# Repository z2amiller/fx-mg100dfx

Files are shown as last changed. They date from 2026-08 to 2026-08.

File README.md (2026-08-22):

# fx-mg100dfx

## MG100DFX Distortion (OD1/OD2)

A pedal port of the overdrive channel from the Marshall MG100DFX solid-state
amp, built for a [PedalPCB forum request][post]. The +/-15V bipolar original is
re-biased for single-supply operation.

### The circuit

Input stage (x11 non-inverting) into a high-gain summing stage that clips into
an antiparallel red/green LED pair across its feedback — even quiet playing
comes out almost as a square wave. The OD1/OD2 switch adds two extra input
branches (more gain, fuller voicing). Marshall-style treble/bass/middle stack,
contour, volume, then a x11 recovery stage.

### Power and headroom

- 9V: fully functional but not completely true to the original tone. The input stage rail-clips hot transients (above roughly 350mV peaks) before the LED clipper.
- 18V: reproduces the original amp's front-end dynamics essentially exactly (sim-verified: identical stage-1 swing to the +/-15V original). Electrolytics are 25V-rated for this.

### No-cap-mult (purist) build

Aggressive power rail filtering is done through a capacitor multiplier at the voltage input. This drops ~1V total between the reverse polarity protection diode and the capacitor multiplier.

If you have a clean supply and want to recover some of the headroom, you can
omit Q1 jumper Q1 pads 2-3 (B and E on the BC547 footprint), and fit 47R at
R23 (Just above the 4-pin connector at the south of the board) instead of 10k.
you get a plain RC filter (47R into ~200uF) — about 34dB less ripple filtering,
about 0.5V less drop. At 18V the saved drop is meaningless — this option is
parts-count preference, not tone.

### Parts notes

- D2/D3 clipping LEDs: use old-school GaP green (Vf ~2.0-2.2V). A modern InGaN green (2.6-2.9V) hits the op-amp rail before the LED clamps at 9V and kills the intended red/green asymmetric clipping.
- Q1 is BC547C (C-B-E). If substituting 2N5088, its pinout is E-B-C — check before soldering.
- Film caps in the signal path, ceramic disc for pF values, per the BOM.
- Hybrid I/O: populate EITHER the JST-PH headers (daughterboard style) OR the PedalPCB-style wire pads (IN at the bottom edge, VIN/GND at top). The daughterboard layout that supports this is at the [pedalfx repo][repo].

[post]: https://forum.pedalpcb.com/threads/help-needed-to-design-od1-od2-pedal-from-mg100dfx-amp.27087/
[repo]: https://github.com/z2amiller/pedalfx/tree/main/template

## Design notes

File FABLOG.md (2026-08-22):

# Fab Log

| Date | Board | Rev | Gen | Gerber SHA256 | JLC Order # | Notes |
|---|---|---|---|---|---|---|
| 2026-08-21T21:19 | fx-mg100dfx | 0.3 | 1 | 51ceb31effab | | |
| 2026-08-21T21:22 | fx-mg100dfx | 0.3 | 2 | 3eab3eaaba2f | | |
| 2026-08-22T16:02 | fx-mg100dfx | 0.4 | 3 | 9177482955ed | | |

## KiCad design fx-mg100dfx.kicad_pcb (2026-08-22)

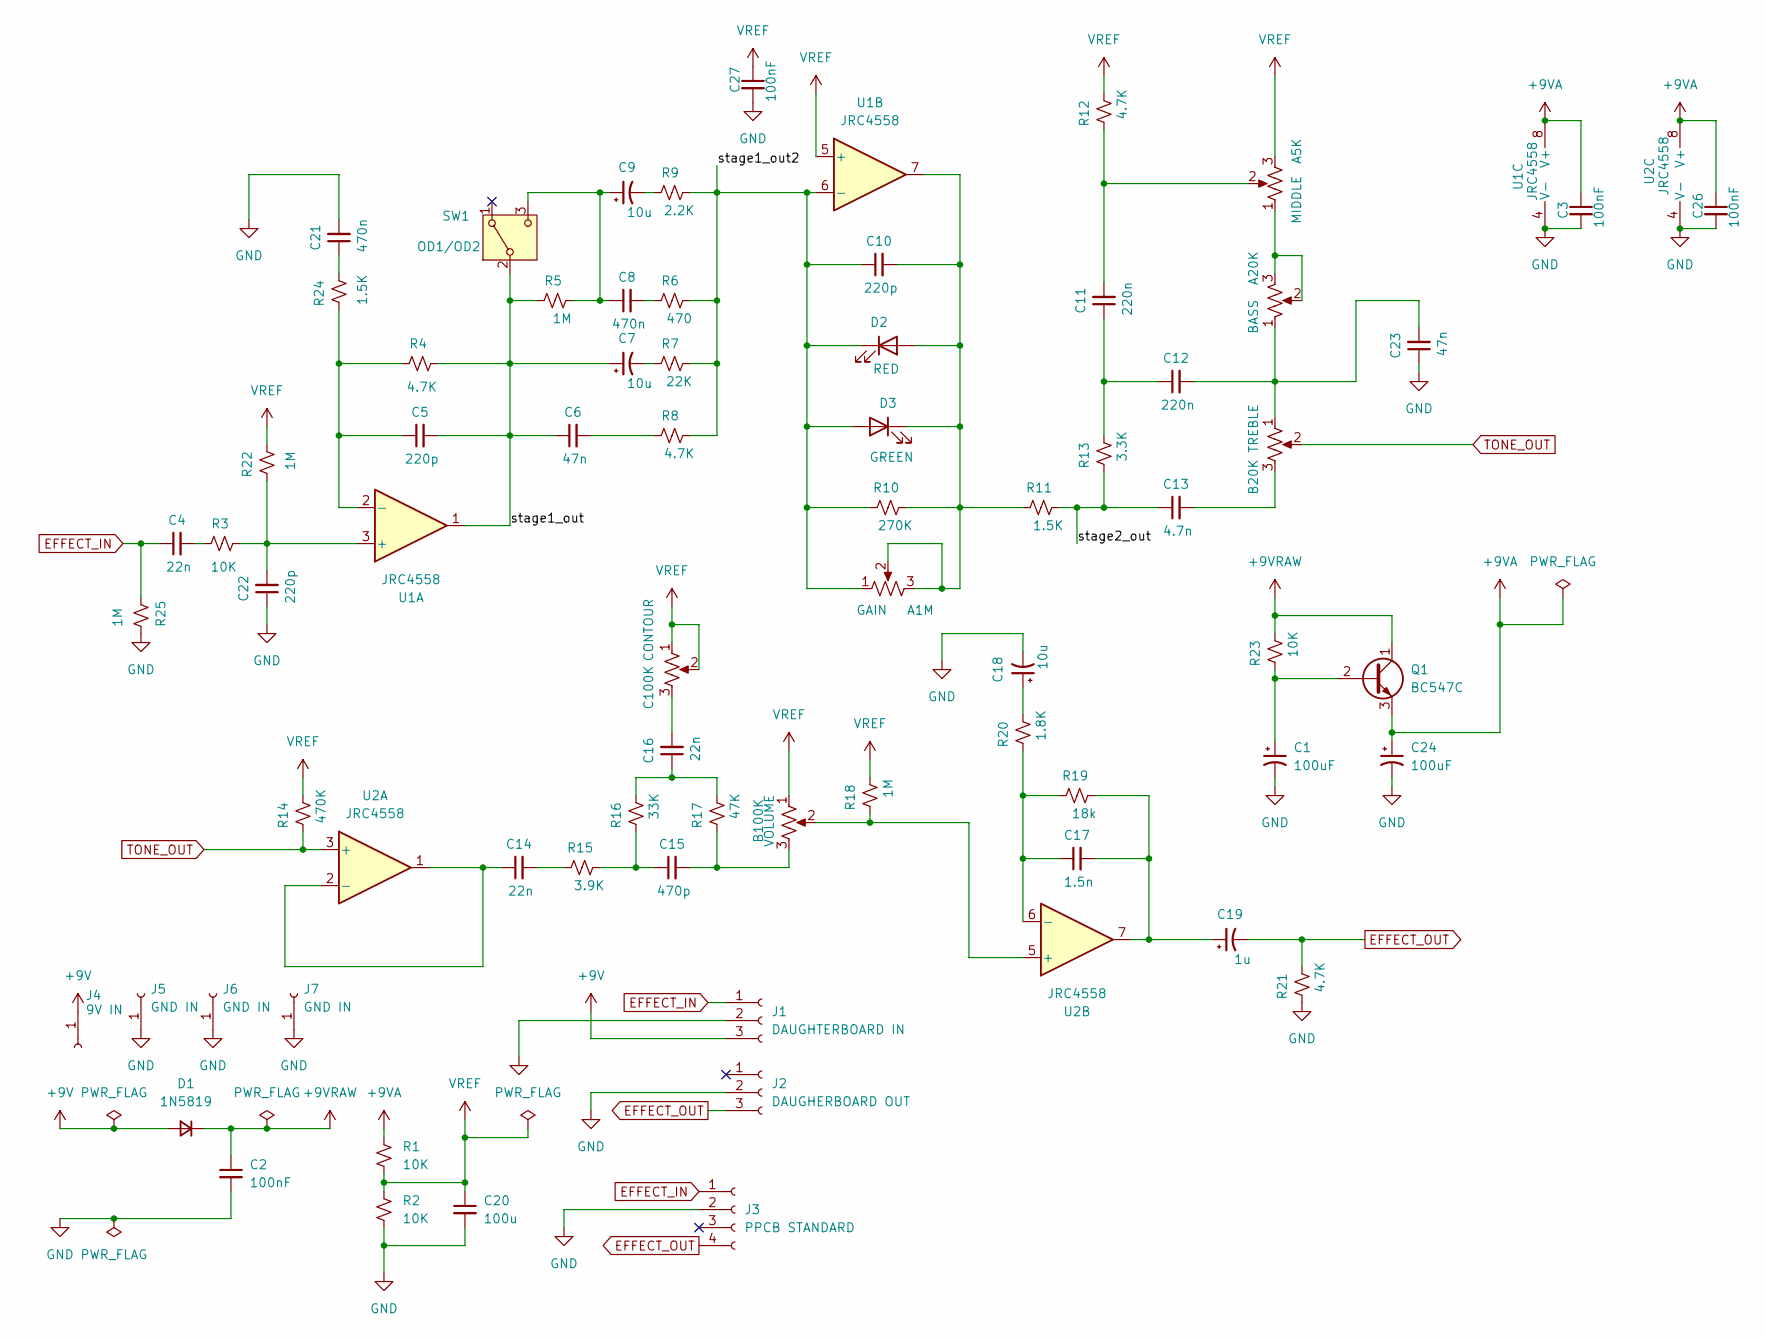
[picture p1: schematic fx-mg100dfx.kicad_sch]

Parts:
C1, C24: 100uF; CP_Radial_D6.3mm_P2.50mm; LCSC C88744
C2, C3, C26, C27: 100nF; C_Disc_D3.4mm_W2.1mm_P2.50mm; LCSC C14663
C4, C14, C16: 22n; C_Rect_L7.2mm_W2.5mm_P5.00mm_FKS2_FKP2_MKS2_MKP2
C5, C10, C22: 220p; C_Disc_D4.3mm_W1.9mm_P5.00mm
C6: 47n; C_Rect_L7.2mm_W2.5mm_P5.00mm_FKS2_FKP2_MKS2_MKP2
C7, C9, C18: 10u; CP_Radial_D5.0mm_P2.00mm
C8, C21: 470n; C_Rect_L7.2mm_W3.5mm_P5.00mm_FKS2_FKP2_MKS2_MKP2
C11, C12: 220n; C_Rect_L7.2mm_W3.0mm_P5.00mm_FKS2_FKP2_MKS2_MKP2
C13: 4.7n; C_Rect_L7.2mm_W2.5mm_P5.00mm_FKS2_FKP2_MKS2_MKP2
C15: 470p; C_Disc_D4.3mm_W1.9mm_P5.00mm
C17: 1.5n; C_Rect_L7.2mm_W2.5mm_P5.00mm_FKS2_FKP2_MKS2_MKP2
C19: 1u; CP_Radial_D5.0mm_P2.00mm
C20: 100u; CP_Radial_D5.0mm_P2.50mm; LCSC C14663
C23: 47n; C_Rect_L7.2mm_W3.0mm_P5.00mm_FKS2_FKP2_MKS2_MKP2
D1: 1N5819; D_DO-41_SOD81_P7.62mm_Horizontal; LCSC C191023
D2: RED; LED_D5.0mm
D3: GREEN; LED_D5.0mm
J1: DAUGHTERBOARD IN; JST_PH_B3B-PH-K_1x03_P2.00mm_Vertical; LCSC C131339
J2: DAUGHERBOARD OUT; JST_PH_B3B-PH-K_1x03_P2.00mm_Vertical; LCSC C131339
J3: PPCB STANDARD; PinHeader_1x04_P2.54mm_Vertical
J4: 9V IN; PinHeader_1x01_P2.54mm_Vertical
J5, J6, J7: GND IN; PinHeader_1x01_P2.54mm_Vertical
Q1: BC547C; TO_92_Inline_Wide
R1, R2, R3, R23: 10K; R_Axial_DIN0207_L6.3mm_D2.5mm_P7.62mm_Horizontal; LCSC C25804
R4, R8, R12, R21: 4.7K; R_Axial_DIN0207_L6.3mm_D2.5mm_P7.62mm_Horizontal; LCSC C25804
R5, R18, R22, R25: 1M; R_Axial_DIN0207_L6.3mm_D2.5mm_P7.62mm_Horizontal; LCSC C25804
R6: 470; R_Axial_DIN0207_L6.3mm_D2.5mm_P7.62mm_Horizontal; LCSC C25804
R7: 22K; R_Axial_DIN0207_L6.3mm_D2.5mm_P7.62mm_Horizontal; LCSC C25804
R9: 2.2K; R_Axial_DIN0207_L6.3mm_D2.5mm_P7.62mm_Horizontal; LCSC C25804
R10: 270K; R_Axial_DIN0207_L6.3mm_D2.5mm_P7.62mm_Horizontal; LCSC C25804
R11, R24: 1.5K; R_Axial_DIN0207_L6.3mm_D2.5mm_P7.62mm_Horizontal; LCSC C25804
R13: 3.3K; R_Axial_DIN0207_L6.3mm_D2.5mm_P7.62mm_Horizontal; LCSC C25804
R14: 470K; R_Axial_DIN0207_L6.3mm_D2.5mm_P7.62mm_Horizontal; LCSC C25804
R15: 3.9K; R_Axial_DIN0207_L6.3mm_D2.5mm_P7.62mm_Horizontal; LCSC C25804
R16: 33K; R_Axial_DIN0207_L6.3mm_D2.5mm_P7.62mm_Horizontal; LCSC C25804
R17: 47K; R_Axial_DIN0207_L6.3mm_D2.5mm_P7.62mm_Horizontal; LCSC C25804
R19: 18k; R_Axial_DIN0207_L6.3mm_D2.5mm_P7.62mm_Horizontal; LCSC C25804
R20: 1.8K; R_Axial_DIN0207_L6.3mm_D2.5mm_P7.62mm_Horizontal; LCSC C25804
RV1: A1M; 16MM_B.MOUNT
RV2: B20K; 16MM_B.MOUNT
RV3: A20K; 16MM_B.MOUNT
RV4: A5K; 16MM_B.MOUNT
RV5: C100K; 16MM_B.MOUNT
RV6: B100K; 16MM_B.MOUNT
SW1: OD1/OD2; SPDT.LUGS
U1, U2: JRC4558; DIP-8_W7.62mm_Socket

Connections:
+9V: D1.2 (A), J1.3, J4.1 (Pin_1_1)
+9VA: C3.1, C24.1, C26.1, Q1.3 (E), R1.2, U1.8 (V+), U2.8 (V+)
+9VRAW: C2.1, D1.1 (K), Q1.1 (C), R23.2
/stage1_out: C5.2, C6.1, C7.1, R4.2, R5.1, SW1.2 (B), U1.1
/stage1_out2: C10.1, D2.1 (K), D3.2 (A), R6.2, R7.2, R8.2, R9.2, R10.1, RV1.1, U1.6 (-)
/stage2_out: C13.1, R11.2, R13.1
EFFECT_IN: C4.1, J1.1, J3.1, R25.1
EFFECT_OUT: C19.2, J2.3, J3.4, R21.2
GND: C1.2, C2.2, C3.2, C18.2, C20.2, C21.2, C22.1, C23.1, C24.2, C26.2, C27.2, J1.2, J2.2, J3.2, J5.1 (Pin_1_1), J6.1 (Pin_1_1), J7.1 (Pin_1_1), R2.2, R21.1, R25.2, U1.4 (V-), U2.4 (V-)
unnamed: C4.2, R3.1
unnamed: C6.2, R8.1
unnamed: C7.2, R7.1
unnamed: C8.2, R6.1
unnamed: C9.2, R9.1
unnamed: C11.1, C12.1, R13.2
unnamed: C11.2, R12.1, RV4.2
unnamed: C12.2, C23.2, RV2.1, RV3.1
unnamed: C13.2, RV2.3
unnamed: C14.2, R15.1
unnamed: C15.1, R15.2, R16.1
unnamed: C15.2, R17.1, RV6.3
unnamed: C16.1, R16.2, R17.2
unnamed: C16.2, RV5.3
unnamed: C17.2, C19.1, R19.2, U2.7
unnamed: C18.1, R20.2
unnamed: C21.1, R24.2
unnamed: C10.2, D2.2 (A), D3.1 (K), R10.2, R11.1, RV1.2, RV1.3, U1.7
unnamed: C1.1, Q1.2 (B), R23.1
unnamed: RV3.2, RV3.3, RV4.1
unnamed: C8.1, C9.1, R5.2, SW1.3 (C)
unnamed: C22.2, R3.2, R22.1, U1.3 (+)
unnamed: C5.1, R4.1, R24.1, U1.2 (-)
unnamed: C14.1, U2.1, U2.2 (-)
unnamed: R18.1, RV6.2, U2.5 (+)
unnamed: C17.1, R19.1, R20.1, U2.6 (-)
TONE_OUT: R14.1, RV2.2, U2.3 (+)
VREF: C20.1, C27.1, R1.1, R2.1, R12.2, R14.2, R18.2, R22.2, RV4.3, RV5.1, RV5.2, RV6.1, U1.5 (+)

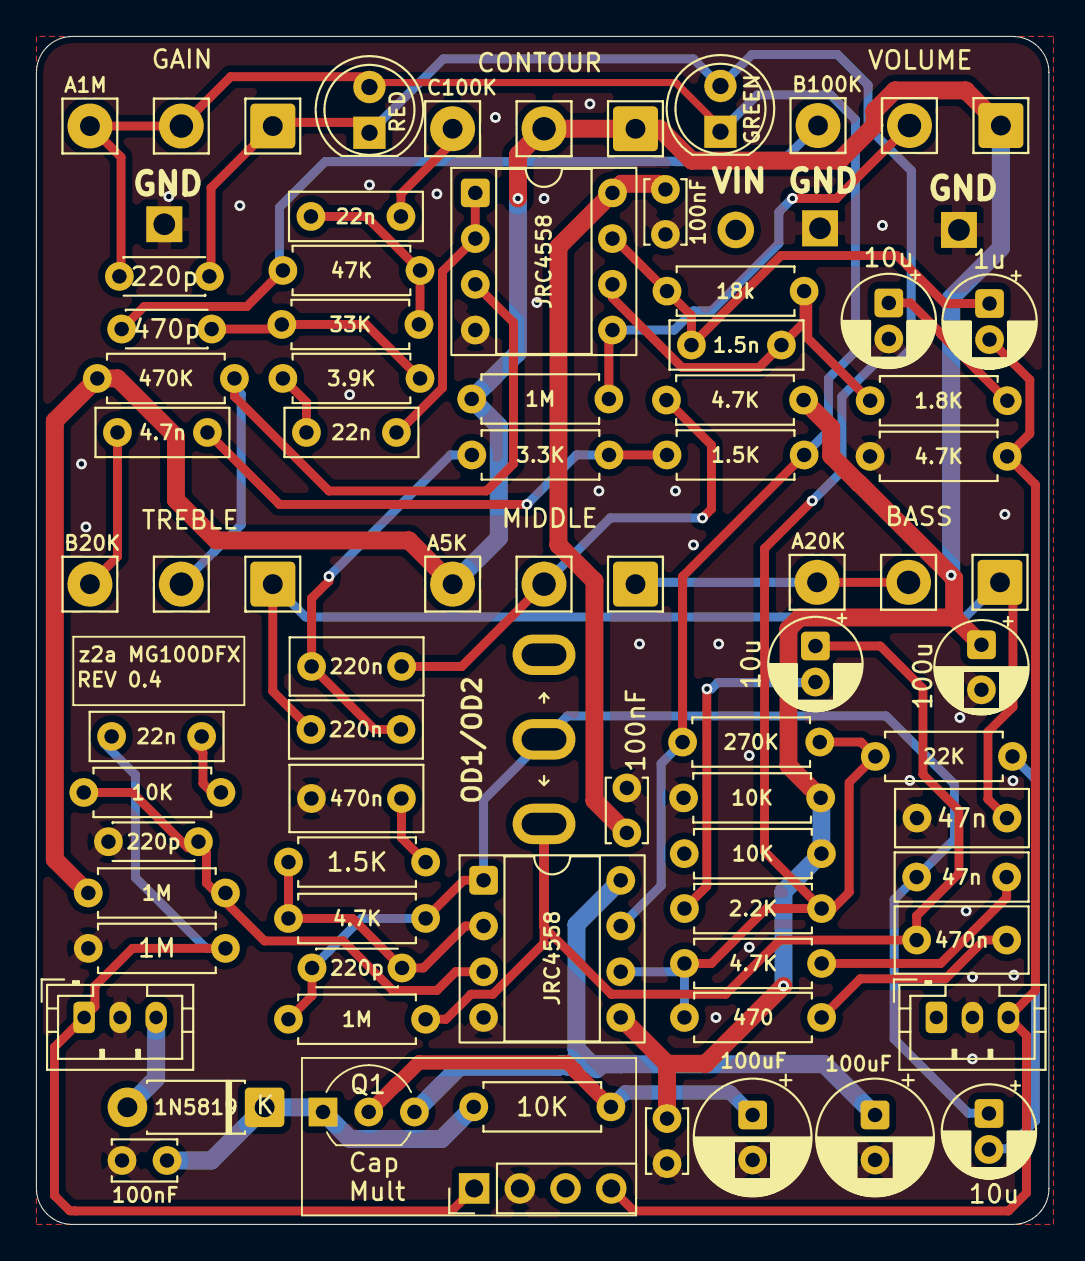
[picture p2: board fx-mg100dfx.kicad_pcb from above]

Board: 4 copper layers, 56.2 x 66.0 mm, 71 parts (0 on the bottom side), 37 nets.

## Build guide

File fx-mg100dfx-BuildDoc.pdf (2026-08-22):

# fx-mg100dfx

## Revision 0.3 · August 21, 2026

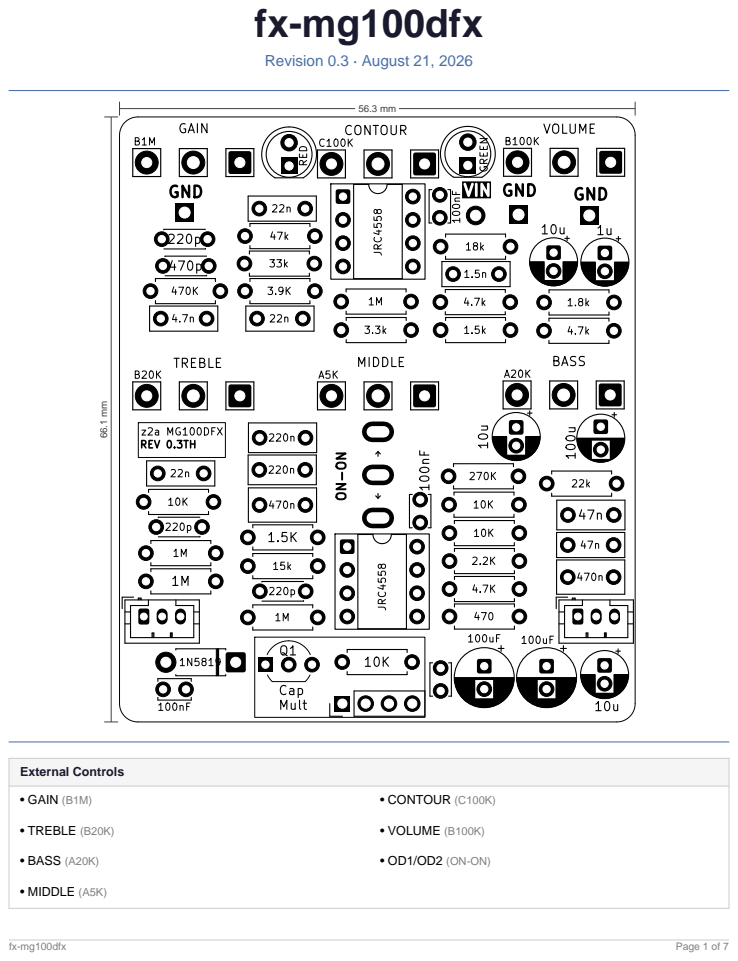
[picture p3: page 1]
fx-mg100dfx; Page 1 of 7; External Controls; • GAIN (B1M); • CONTOUR (C100K); • TREBLE (B20K); • VOLUME (B100K); • BASS (A20K); • MIDDLE (A5K); z2a MG100DFX REV 0.3TH; Cap Mult; GND; 1.5k ¹⁰⁰nF; VOLUME; RED; CONTOUR; BASS; MIDDLE; JRC4558; 1.8k GREEN; TREBLE; JRC455815k; GAIN

# fx-mg100dfx

## Parts List

LOCATION | VALUE | TYPE | NOTES
C1 | 100uF | Electrolytic Bulk Capacitor | 25V min, 35V better - Base cap for multiplier
C2 | 100nF | Unpolarized capacitor, small symbol - X7R MLCC
C3 | 100nF | Unpolarized capacitor, small symbol - X7R MLCC
C4 | 22n | Unpolarized capacitor, small symbol
C5 | 220p | Capacitor
C6 | 47n | Unpolarized capacitor, small symbol
C7 | 10u | Capacitor
C8 | 470n | Unpolarized capacitor, small symbol
C9 | 10u | Capacitor
C10 | 220p | Capacitor
C11 | 220n | Unpolarized capacitor, small symbol
C12 | 220n | Unpolarized capacitor, small symbol
C13 | 4.7n | Unpolarized capacitor, small symbol
C14 | 22n | Unpolarized capacitor, small symbol
C15 | 470p | Capacitor
C16 | 22n | Unpolarized capacitor, small symbol
C17 | 1.5n | Unpolarized capacitor, small symbol
C18 | 10u | Capacitor
C19 | 1u | Capacitor
C20 | 100u | Electrolytic Bulk Capacitor | 25V min, 35V better
C21 | 470n | Capacitor
C22 | 220p | Capacitor
C23 | 47n | Unpolarized capacitor, small symbol
C24 | 100uF | Electrolytic Bulk Capacitor | 25V min, 35V better
C26 | 100nF | Unpolarized capacitor, small symbol - X7R MLCC
C27 | 100nF | Unpolarized capacitor, small symbol - X7R MLCC
D1 | 1N5819 | Diode
D2 | RED | Light emitting diode
D3 | GREEN | Light emitting diode

LOCATION | VALUE | TYPE | NOTES
J1 | DAUGHTERBOA RD IN | Generic connector, single row, 01x03, script generated
J2 | DAUGHERBOAR D OUT | Generic connector, single row, 01x03, script generated
J3 | PPCB STANDARD | Generic connector, single row, 01x04, script generated
J4 | 9V IN | Generic connector, single row, 01x01, script generated
J5 | GND IN | Generic connector, single row, 01x01, script generated
J6 | GND IN | Generic connector, single row, 01x01, script generated
J7 | GND IN | Generic connector, single row, 01x01, script generated
Q1 | BC547C | 0.1A Ic, 45V Vce, Small Signal NPN Transistor, TO-92
R1 | 10K | Resistor, small US symbol
R2 | 10K | Resistor, small US symbol
R3 | 10K | Resistor, small US symbol
R4 | 15k | Resistor, small US symbol
R5 | 1M | Resistor, small US symbol
R6 | 470 | Resistor, small US symbol
R7 | 22k | Resistor, small US symbol
R8 | 4.7K | Resistor, small US symbol
R9 | 2.2K | Resistor, small US symbol
R10 | 270K | Resistor, small US symbol
R11 | 1.5k | Resistor, small US symbol
R12 | 4.7k | Resistor, small US symbol
R13 | 3.3k | Resistor, small US symbol
R14 | 470K | Resistor, small US symbol
R15 | 3.9K | Resistor, small US symbol
R16 | 33k | Resistor, small US symbol
R17 | 47k | Resistor, small US symbol
R18 | 1M | Resistor, small US symbol
R19 | 18k | Resistor, small US symbol
R20 | 1.8k | Resistor, small US symbol
R21 | 4.7k | Resistor, small US symbol
R22 | 1M | Resistor, small US symbol

LOCATION | VALUE | TYPE | NOTES
R23 | 10K | Resistor, small US symbol | Cap Multiplier Base (See Note)
R24 | 1.5K | Resistor, small US symbol
R25 | 1M | Resistor, small US symbol
U1 | JRC4558 | Dual Low-Noise Operational Amplifiers, DIP-8/SOIC-8
U2 | JRC4558 | Dual Low-Noise Operational Amplifiers, DIP-8/SOIC-8
BASS | A20K | Potentiometer, US symbol
CONTOUR | C100K | Potentiometer, US symbol
GAIN | B1M | Potentiometer, US symbol
MIDDLE | A5K | Potentiometer, US symbol
OD1/OD2 | ON-ON | Switch, single pole double throw
TREBLE | B20K | Potentiometer, US symbol
VOLUME | B100K | Potentiometer, US symbol

## +9VAV-

VREF | VREF | 1

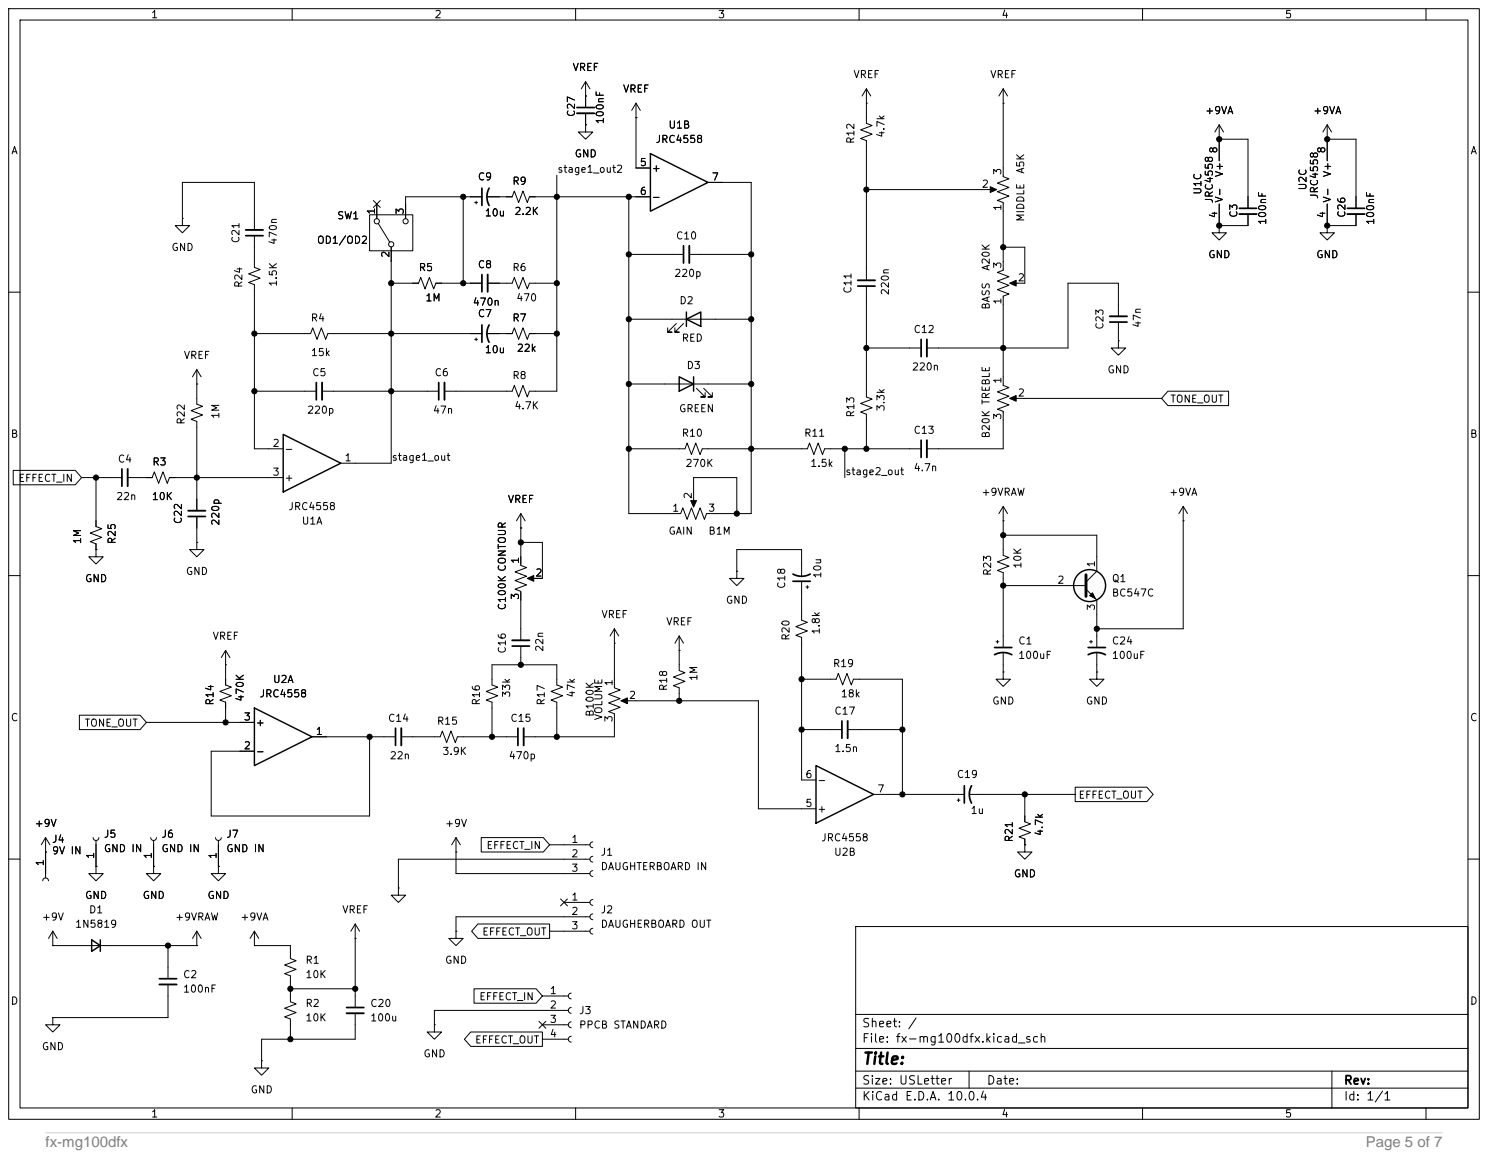
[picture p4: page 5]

## fx-mg100dfx — Enclosure Drilling Template

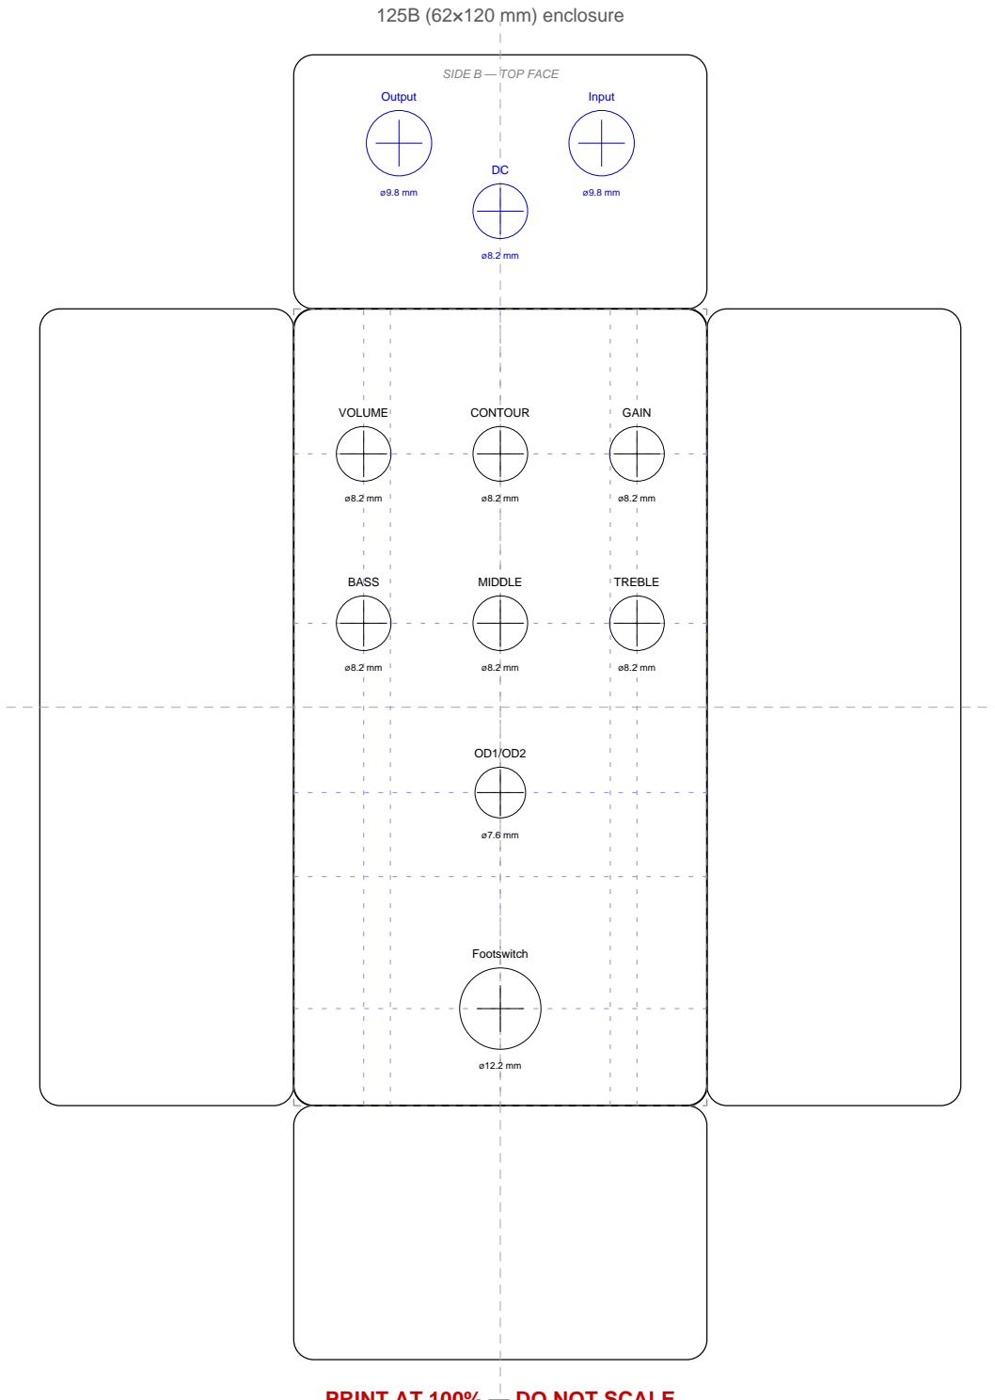
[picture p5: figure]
VOLUME; CONTOUR; GAIN; ø8.2 mm BASS; ø8.2 mm MIDDLE; ø8.2 mm TREBLE; Footswitch; SIDE B — TOP FACE; Output; Input; 125B (62×120 mm) enclosure

PRINT AT 100% — DO NOT SCALE

macOS: Print → Scale: 100% • Verify scale bar below measures exactly 25 mm before drilling

25 mm

# fx-mg100dfx

## Tayda Drill Manifest — 125B (62×120 mm)

X/Y are mm from the centre of each face (positive Y = toward front). Side A = front face. Side B = top face. Side C = left face (rotated -R enclosures).

SIDE | DIAMETER (mm) | X (mm) | Y (mm) | LABEL
A | 8.2 | -20.5 | 38.0 | VOLUME
A | 8.2 | 0.0 | 38.0 | CONTOUR
A | 8.2 | 20.5 | 38.0 | GAIN
A | 8.2 | -20.5 | 12.6 | BASS
A | 8.2 | 0.0 | 12.6 | MIDDLE
A | 8.2 | 20.5 | 12.6 | TREBLE
A | 7.6 | 0.0 | -12.8 | OD1/OD2
A | 12.2 | 0.0 | -45.2 | Footswitch
B | 8.2 | 0.0 | 4.4 | DC
B | 9.8 | -15.2 | -5.8 | Output
B | 9.8 | 15.2 | -5.8 | Input

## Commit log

2026-08-22 KiCad files
    [fx-mg100dfx-thd.kicad_sch, fx-mg100dfx.kicad_pcb, fx-mg100dfx.kicad_sch]
2026-08-22 Checkpoint PCB (description diffs)
    [fx-mg100dfx.kicad_pcb]
2026-08-22 fx-mg100dfx 0.3 fab outputs (g1)
    [fx-mg100dfx.kicad_pcb, fx-mg100dfx.kicad_sch]
2026-08-22 Add the gerbers directly
2026-08-22 fx-mg100dfx 0.4 fab outputs (g3)
    [fx-mg100dfx.kicad_pcb, fx-mg100dfx.kicad_sch]
2026-08-22 Add the gerbers explicitly
2026-09-13 Delete fx-mg100dfx-thd.kicad_sch
    delete old schematic copy
    [fx-mg100dfx-thd.kicad_sch]
